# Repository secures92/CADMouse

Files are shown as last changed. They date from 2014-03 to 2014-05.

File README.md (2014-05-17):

CADMouse
========

fully 3D printable CAD-Mouse with host software for solidworks.

CAD-Mouse is connected as Joystick. Windows host software translates Axis movements to Solidworks view translation commands.
(Any standard joystick could be use)

Thingiverse: http://www.thingiverse.com/thing:260830
Warning : some parts have been upgraded, check latest version on github.

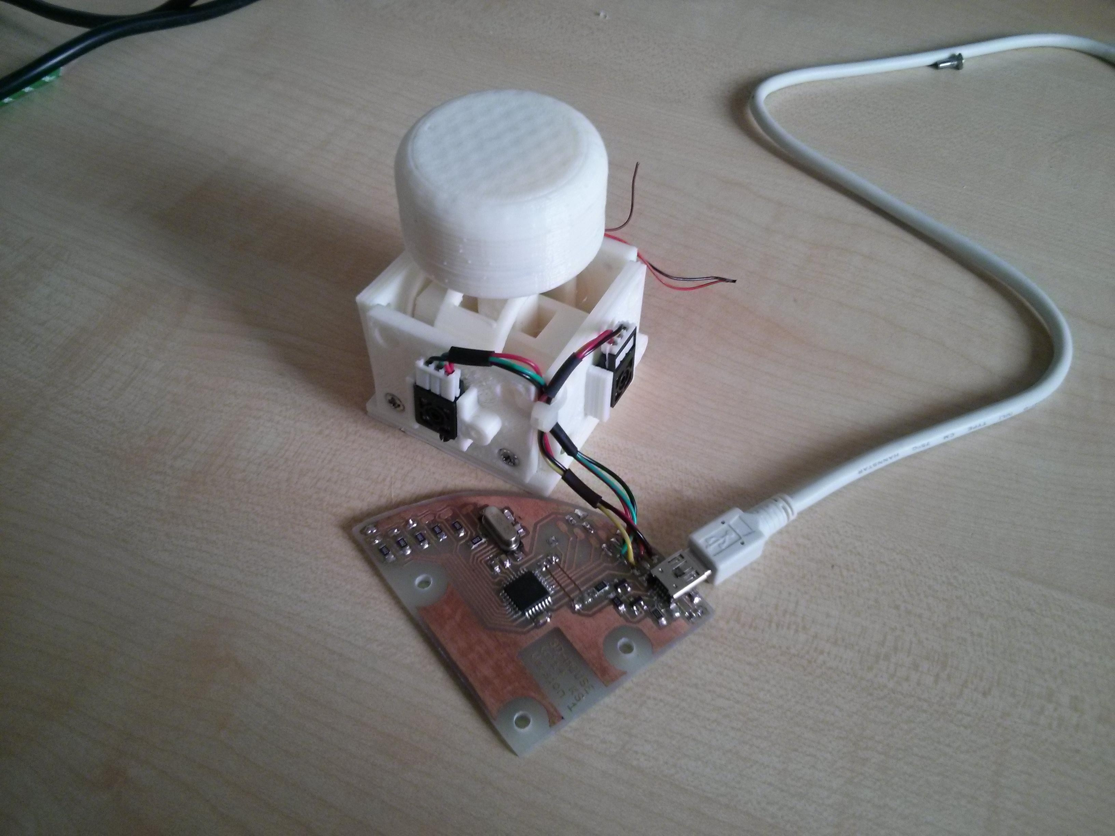
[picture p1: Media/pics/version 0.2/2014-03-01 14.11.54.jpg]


Video
------
New top spring and added translate / zoom :
IMAGE ALT TEXT HERE (http://youtu.be/kaDWCsqc0LQ)

Original demo
IMAGE ALT TEXT HERE (http://youtu.be/4gp94MjgFCs)

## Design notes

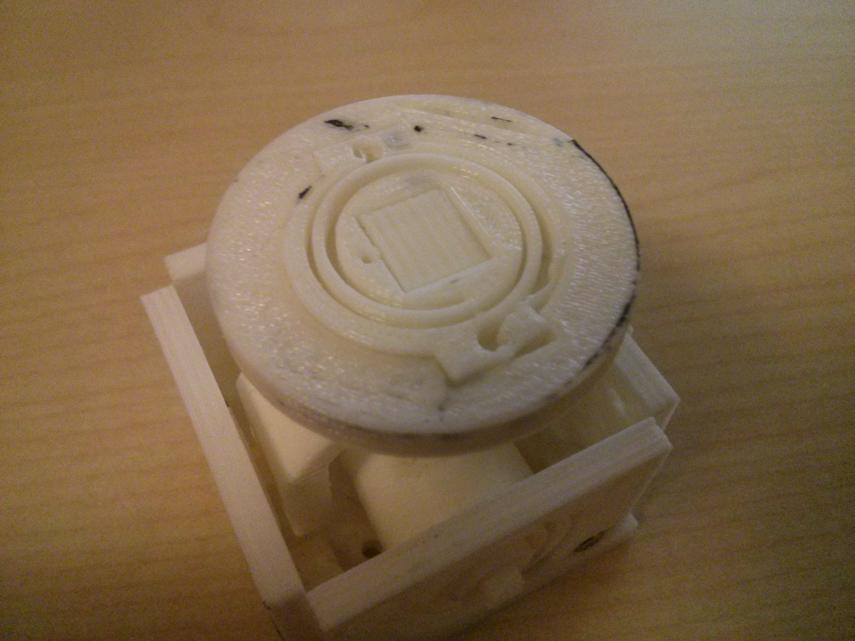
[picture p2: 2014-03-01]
Media/pics/version 0.2/2014-02-27 22.28.41.jpg

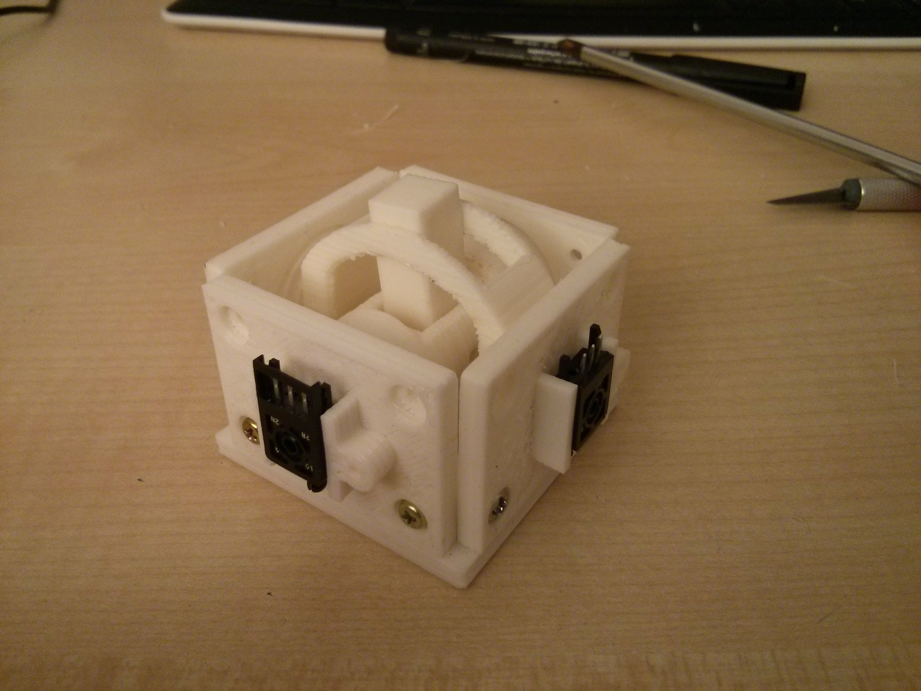
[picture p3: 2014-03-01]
Media/pics/version 0.2/2014-02-24 00.38.57.jpg

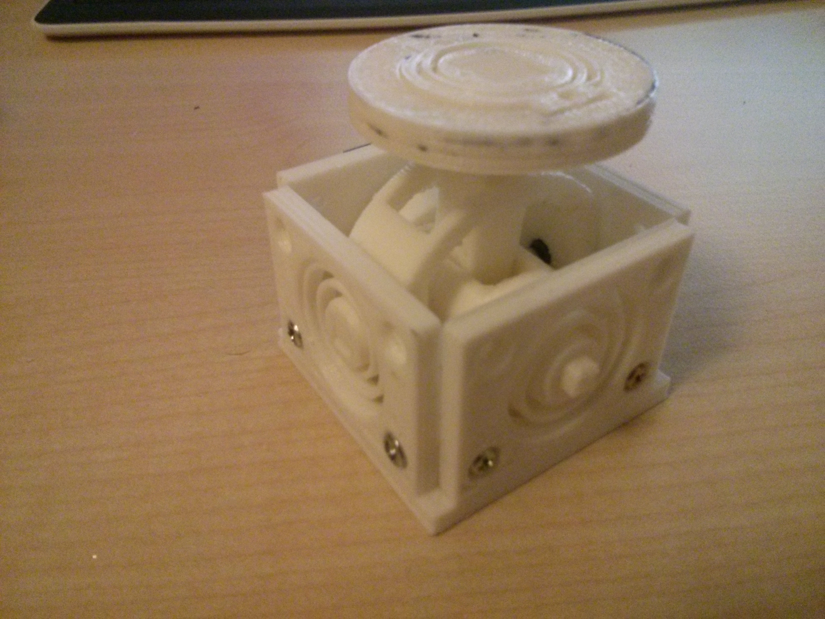
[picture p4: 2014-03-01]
Media/pics/version 0.2/2014-02-27 22.28.56.jpg

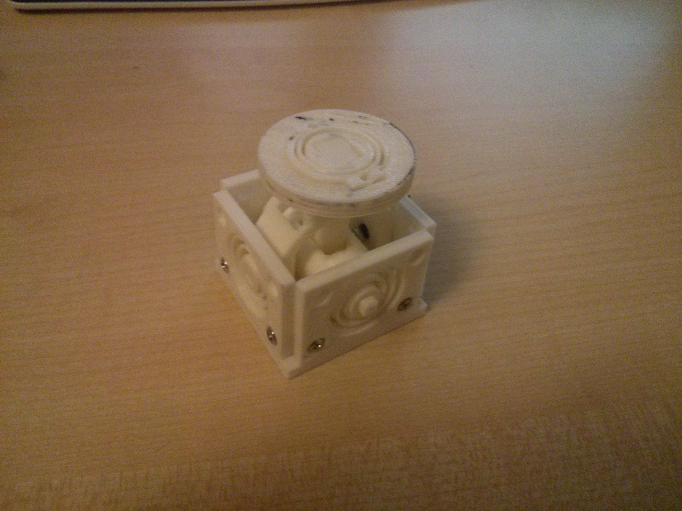
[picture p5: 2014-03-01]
Media/pics/version 0.2/2014-02-27 22.28.31.jpg

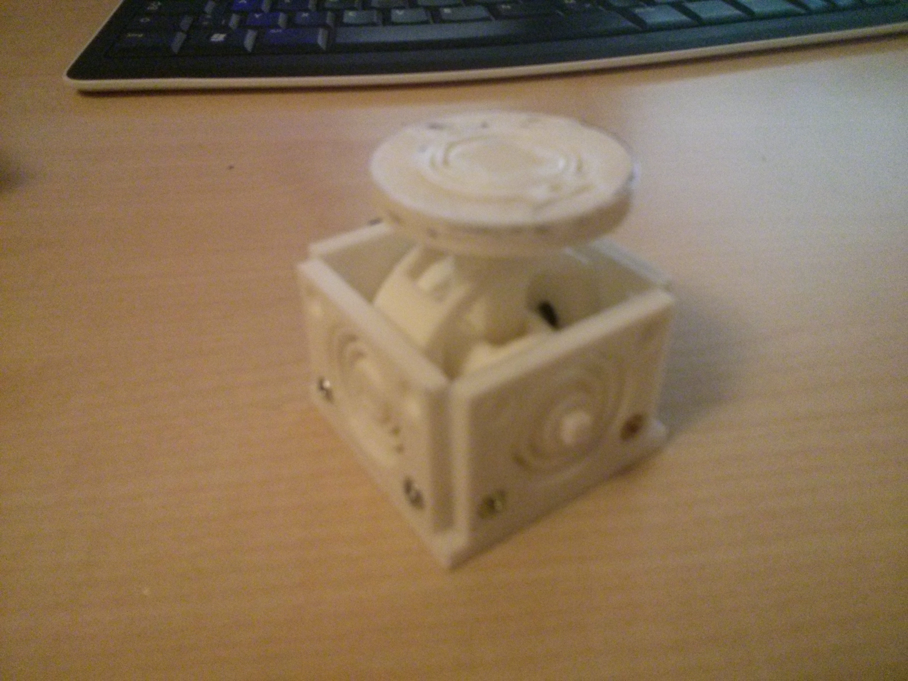
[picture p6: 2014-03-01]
Media/pics/version 0.2/2014-02-27 22.29.02.jpg

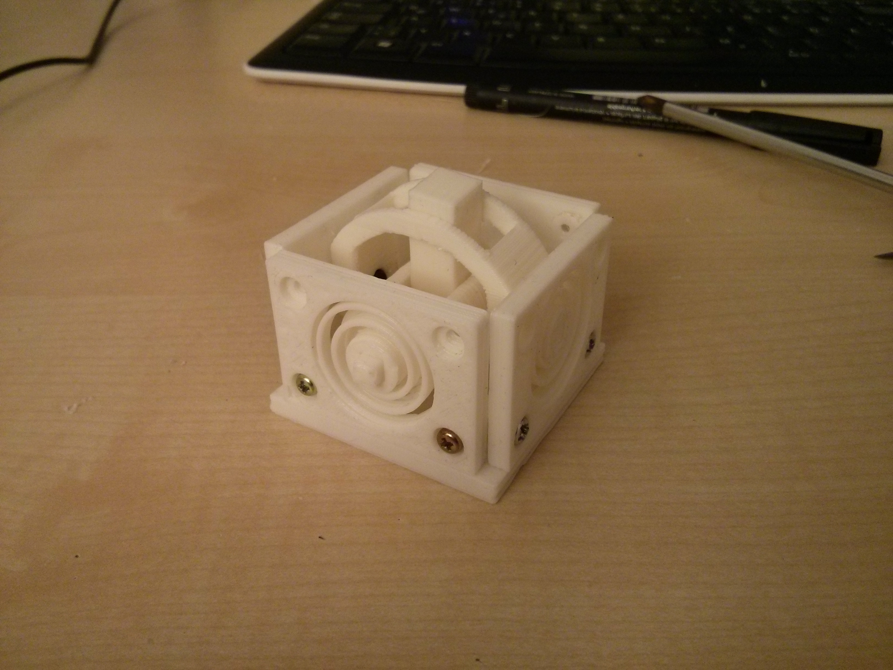
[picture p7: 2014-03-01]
Media/pics/version 0.2/2014-02-24 00.38.48.jpg

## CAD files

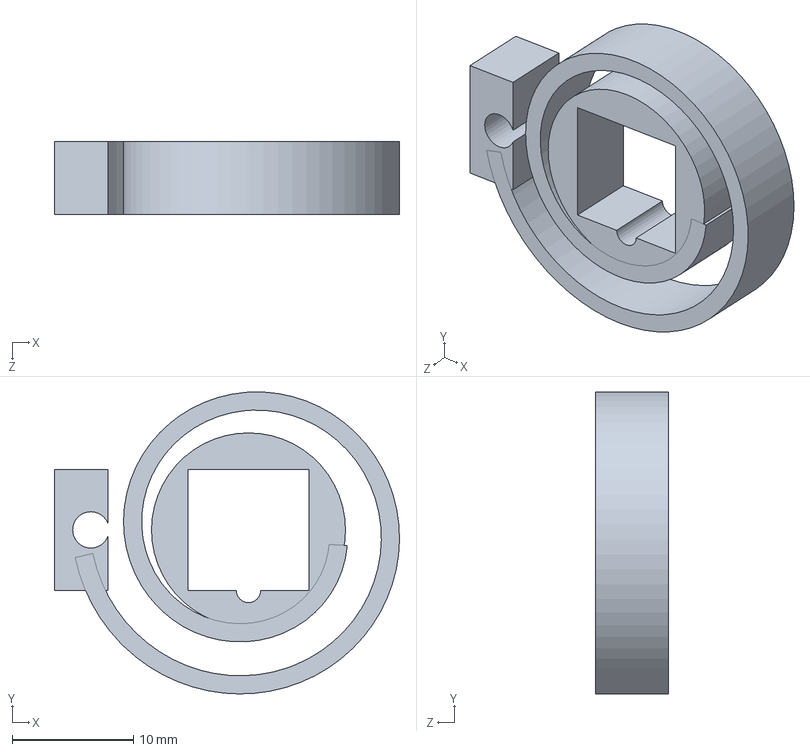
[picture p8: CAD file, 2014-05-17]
SolidWorks/Version 0.4/top_spring_3.SLDPRT
28.5 x 24.9 x 6.00 mm

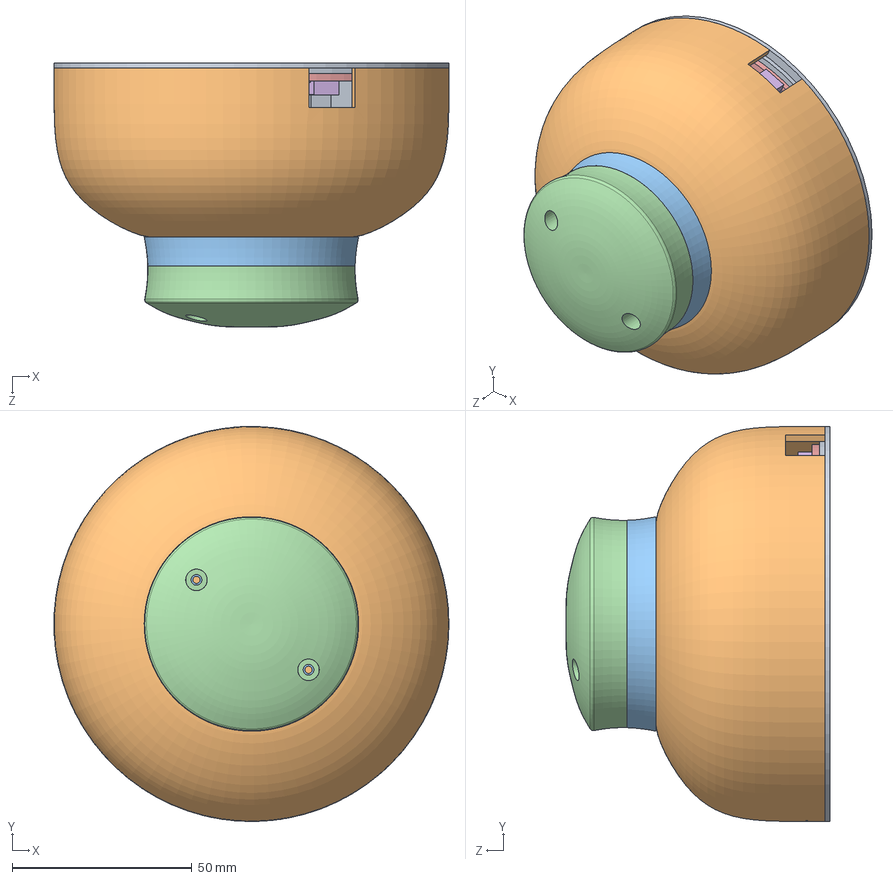
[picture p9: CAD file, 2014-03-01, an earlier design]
SolidWorks/Version 0.1/3DMaus.SLDASM
110.0 x 110.0 x 73.6 mm
bottom
case
KnobBottom
KnobTop
pcb
components

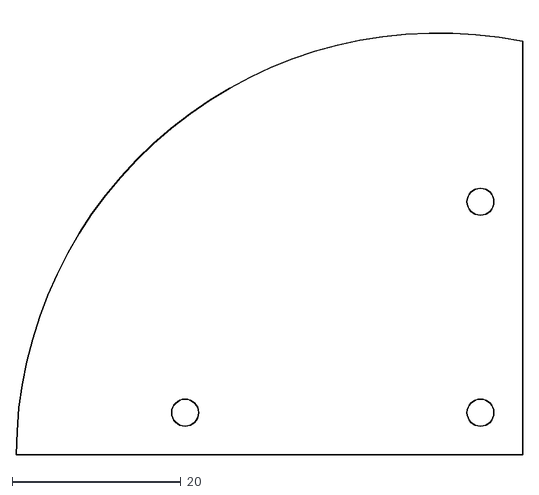
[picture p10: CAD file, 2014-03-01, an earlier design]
Eagle/Version 0.1/AtMega88.dxf
60.0 x 52.0

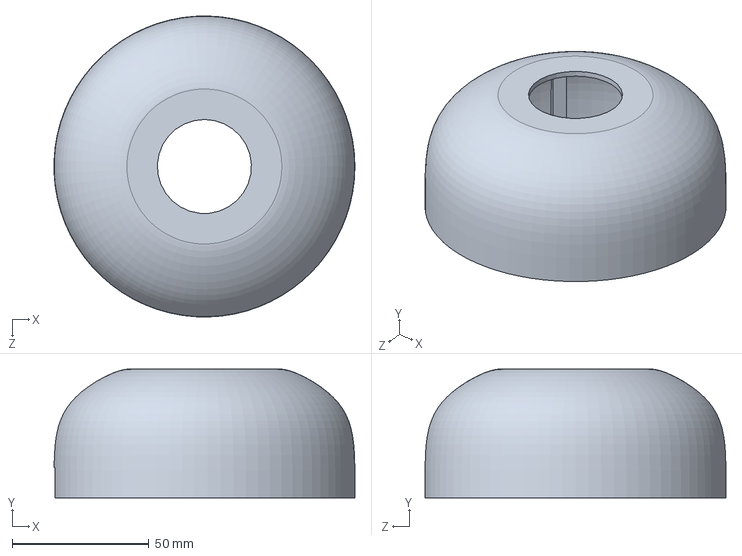
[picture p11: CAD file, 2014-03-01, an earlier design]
SolidWorks/Version 0.1/case.SLDPRT
109.9 x 47.0 x 110.0 mm

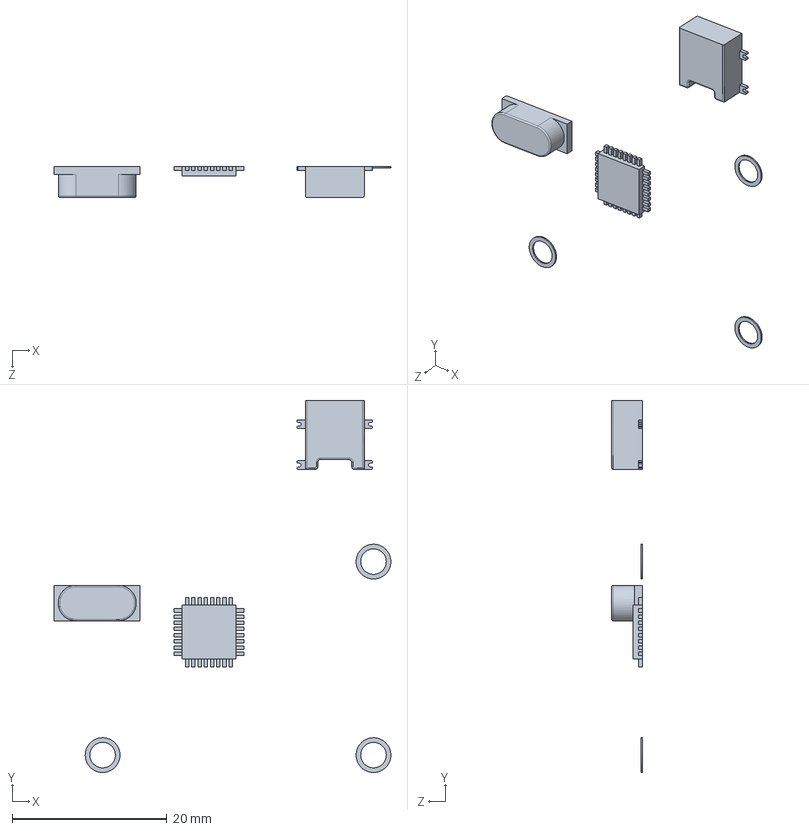
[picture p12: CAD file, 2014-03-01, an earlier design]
SolidWorks/Version 0.1/pcb/components.SLDPRT
43.5 x 48.1 x 4.00 mm

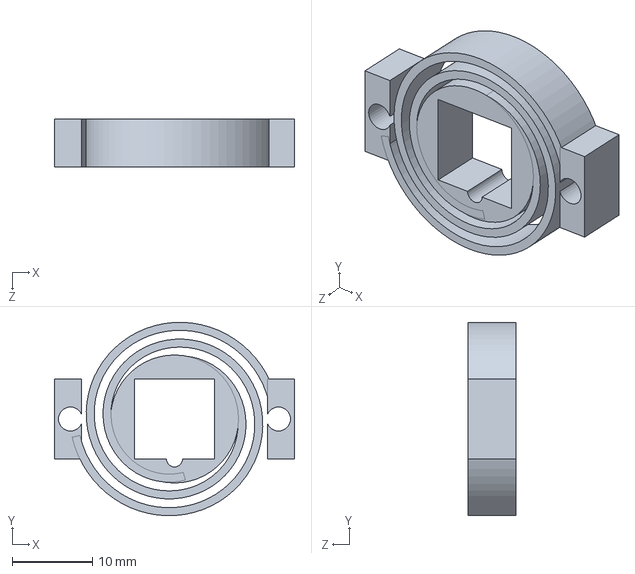
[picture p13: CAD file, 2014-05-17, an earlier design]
SolidWorks/Version 0.3/top_spring_2.SLDPRT
30.0 x 24.2 x 6.00 mm

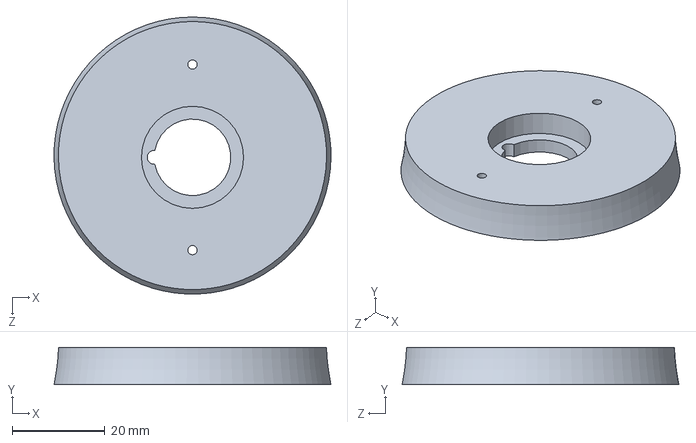
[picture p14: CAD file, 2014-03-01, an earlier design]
SolidWorks/Version 0.1/KnobBottom.SLDPRT
59.7 x 8.00 x 59.7 mm

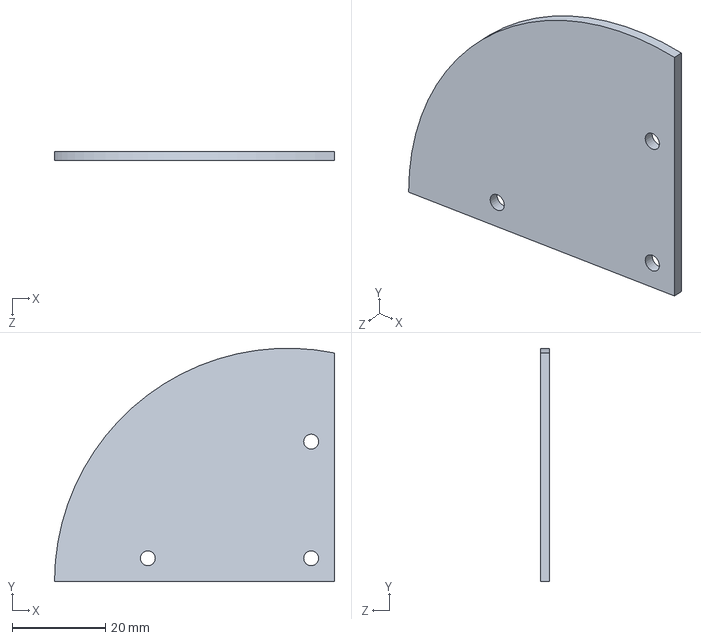
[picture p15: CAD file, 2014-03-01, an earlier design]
SolidWorks/Version 0.1/pcb/pcb.SLDPRT
60.0 x 50.0 x 2.00 mm

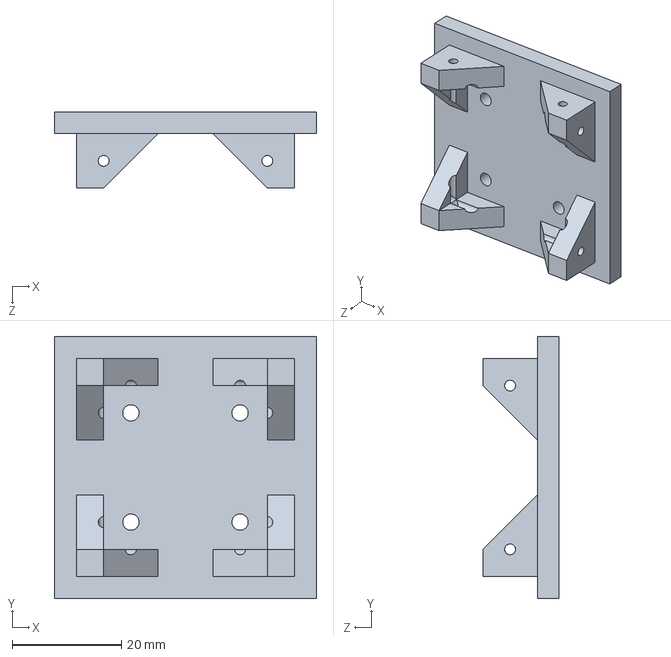
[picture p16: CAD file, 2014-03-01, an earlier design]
SolidWorks/Version 0.2/base.SLDPRT
48.0 x 48.0 x 14.0 mm

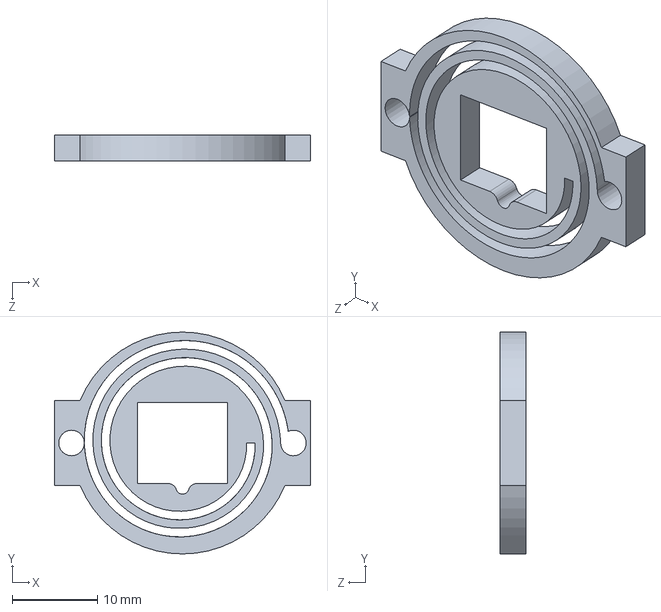
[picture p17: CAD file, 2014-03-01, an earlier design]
SolidWorks/Version 0.2/top_spring.SLDPRT
30.0 x 26.0 x 3.00 mm

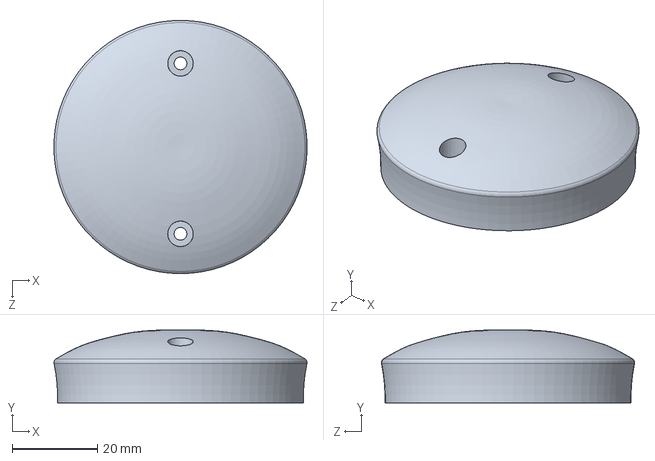
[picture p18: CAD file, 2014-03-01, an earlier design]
SolidWorks/Version 0.1/KnobTop.SLDPRT
59.4 x 17.1 x 59.4 mm

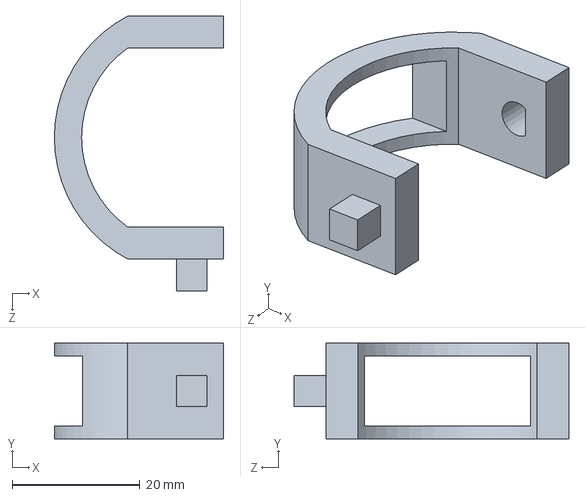
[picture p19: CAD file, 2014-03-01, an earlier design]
SolidWorks/Version 0.2/rod-bow.SLDPRT
26.5 x 15.0 x 43.0 mm

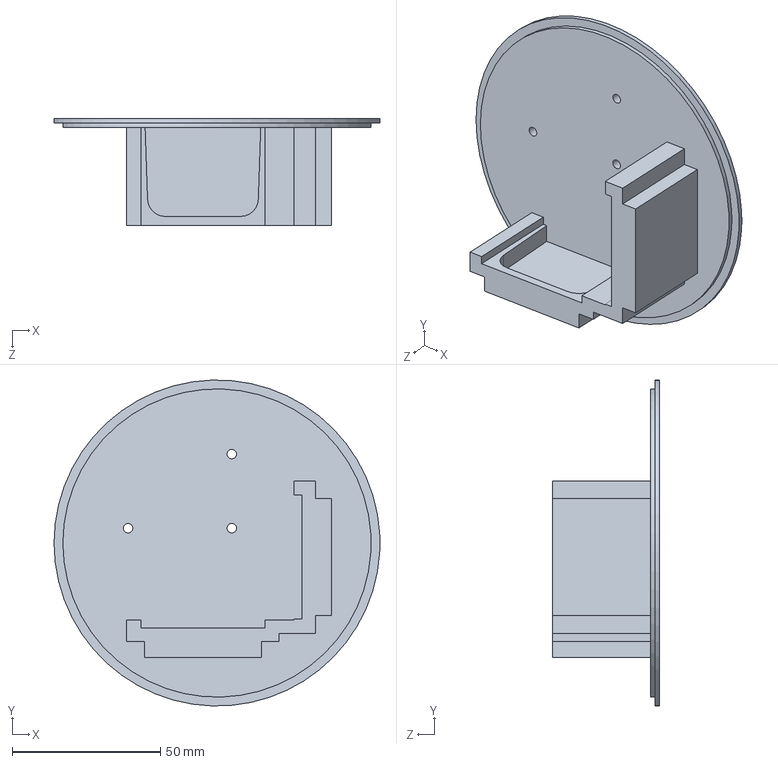
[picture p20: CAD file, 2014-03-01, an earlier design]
SolidWorks/Version 0.1/bottom_1.SLDPRT
110.0 x 110.0 x 36.0 mm

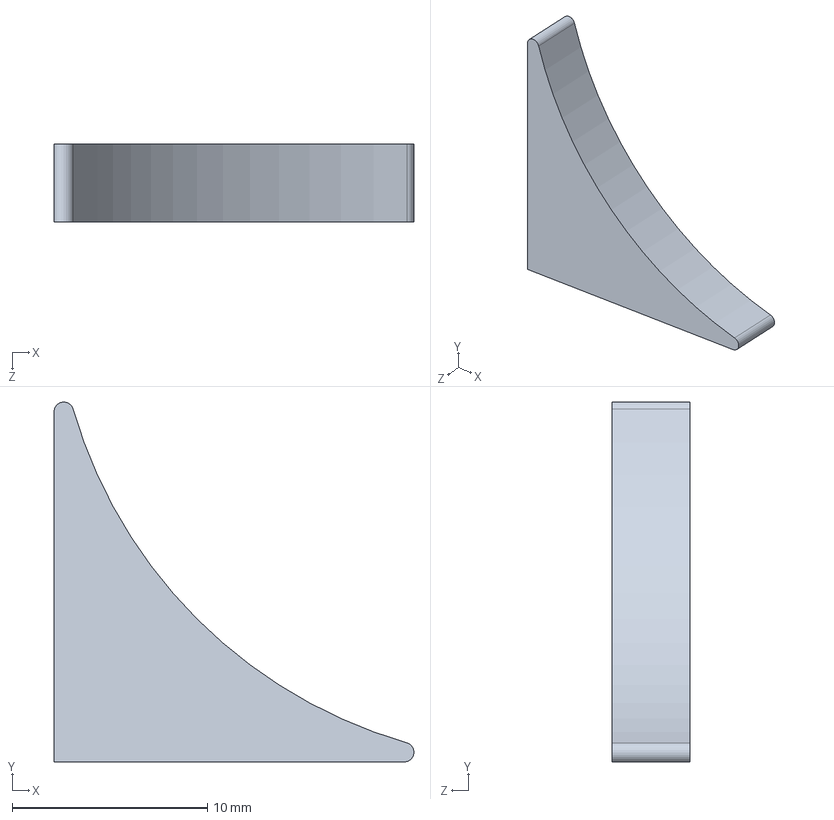
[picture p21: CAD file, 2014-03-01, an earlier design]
SolidWorks/Version 0.2/top.SLDPRT
18.4 x 18.4 x 4.00 mm

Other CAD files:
SolidWorks/Version 0.1/bottom.SLDPRT
SolidWorks/Version 0.2/spring_wall.SLDPRT
SolidWorks/Version 0.1/connector.SLDPRT
Eagle/Version 0.1/AtMega88_.dxf
SolidWorks/Version 0.1/STL/KnobBottom.STL
SolidWorks/Version 0.1/STL/KnobTop.STL
SolidWorks/Version 0.1/STL/bottom.STL
SolidWorks/Version 0.1/STL/case.STL
SolidWorks/Version 0.1/STL/connector.STL
SolidWorks/Version 0.1/bottom_alt.SLDPRT
SolidWorks/Version 0.2/case.SLDPRT
SolidWorks/Version 0.2/knob_bottom.SLDPRT
SolidWorks/Version 0.2/knob_top.SLDPRT
SolidWorks/Version 0.2/plate_bottom.SLDPRT
SolidWorks/Version 0.2/poti_spring_wall.SLDPRT
SolidWorks/Version 0.2/poti_wall.SLDPRT
SolidWorks/Version 0.2/rod.SLDPRT
SolidWorks/Version 0.2/stick.SLDPRT
SolidWorks/Version 0.2/stl/base.STL
SolidWorks/Version 0.2/stl/case.STL
SolidWorks/Version 0.2/stl/knob_bottom.STL
SolidWorks/Version 0.2/stl/knob_top.STL
SolidWorks/Version 0.2/stl/poti_wall.STL
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

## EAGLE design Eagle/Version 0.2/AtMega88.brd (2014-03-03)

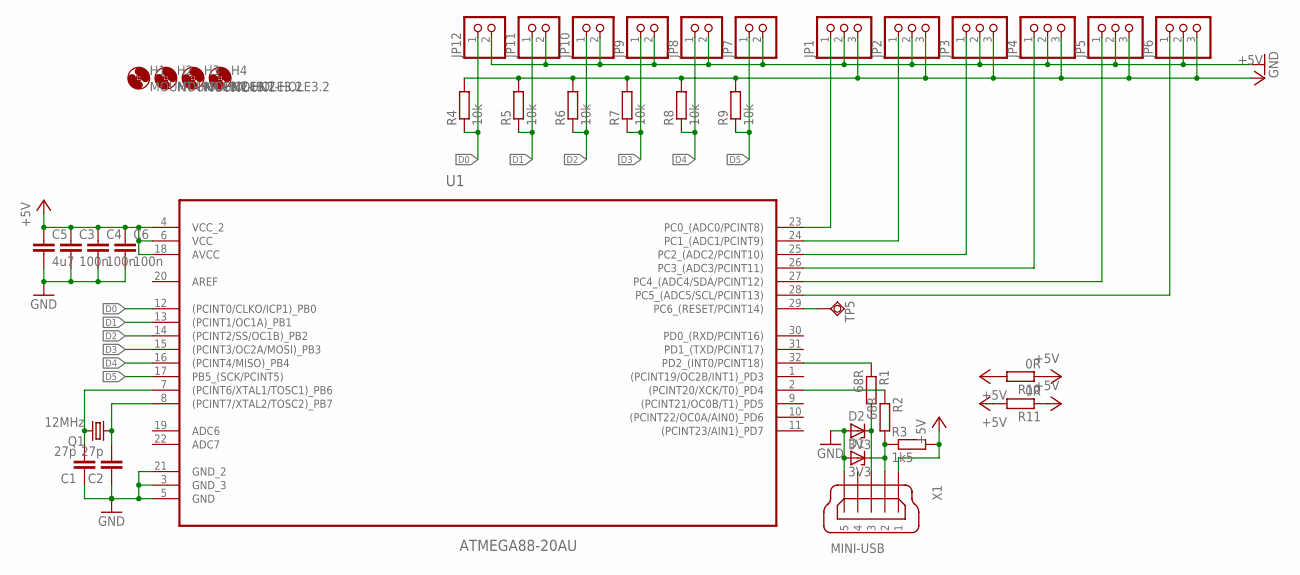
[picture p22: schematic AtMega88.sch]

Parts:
C1, C2: 27p; C0805
C3, C4, C6: 100n; C0805
C5: 4u7; C0805
D1, D2: 3V3; SOT23
H1, H2, H3, H4: MOUNT-HOLE3.2; 3,2
JP1, JP2, JP3, JP4, JP5, JP6: PINHD-1X3; 1X03
JP7, JP8, JP9, JP10, JP11, JP12: PINHD-1X2; 1X02
Q1: 12MHz; CSM-7X-DU
R1, R2: 68R; R1206
R3: 1k5; R1206
R4, R5, R6, R7, R8, R9: 10k; R1206
R10, R11: 0R; R1206
TP5: TPSQTP20SQ; TP20SQ
U1: ATMEGA88-20AU; QFP80P900X900X120-32N
X1: MINI-USB; UX60A-MB-5ST

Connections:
+5V: C3.1, C4.1, C5.1, C6.1, JP1.3, JP2.3, JP3.3, JP4.3, JP5.3, JP6.3, R3.2, R4.2, R5.2, R6.2, R7.2, R8.2, R9.2, R10.1, R10.2, R11.1, R11.2, U1.4 (VCC_2), U1.6 (VCC), U1.18 (AVCC), X1.1
A0: JP1.1, U1.23 (PC0_(ADC0/PCINT8))
A1: JP2.1, U1.24 (PC1_(ADC1/PCINT9))
A2: JP3.1, U1.25 (PC2_(ADC2/PCINT10))
A3: JP4.1, U1.26 (PC3_(ADC3/PCINT11))
A4: JP5.1, U1.27 (PC4_(ADC4/SDA/PCINT12))
A5: JP6.1, U1.28 (PC5_(ADC5/SCL/PCINT13))
D0: JP12.1, R4.1, U1.12 ((PCINT0/CLKO/ICP1)_PB0)
D1: JP11.1, R5.1, U1.13 ((PCINT1/OC1A)_PB1)
D2: JP10.1, R6.1, U1.14 ((PCINT2/SS/OC1B)_PB2)
D3: JP9.1, R7.1, U1.15 ((PCINT3/OC2A/MOSI)_PB3)
D4: JP8.1, R8.1, U1.16 ((PCINT4/MISO)_PB4)
D5: JP7.1, R9.1, U1.17 (PB5_(SCK/PCINT5))
GND: C1.1, C2.1, C3.2, C4.2, C5.2, C6.2, D1.1 (A), D2.1 (A), JP1.2, JP2.2, JP3.2, JP4.2, JP5.2, JP6.2, JP7.2, JP8.2, JP9.2, JP10.2, JP11.2, JP12.2, U1.3 (GND_3), U1.5 (GND), U1.21 (GND_2), X1.5
unnamed: C1.2, Q1.2, U1.7 ((PCINT6/XTAL1/TOSC1)_PB6)
unnamed: C2.2, Q1.1, U1.8 ((PCINT7/XTAL2/TOSC2)_PB7)
unnamed: R1.1, U1.32 (PD2_(INT0/PCINT18))
unnamed: R2.1, U1.2 ((PCINT20/XCK/T0)_PD4)
unnamed: D2.3 (C), R1.2, X1.3
unnamed: D1.3 (C), R2.2, R3.1, X1.2
unnamed: TP5.TP, U1.29 (PC6_(RESET/PCINT14))

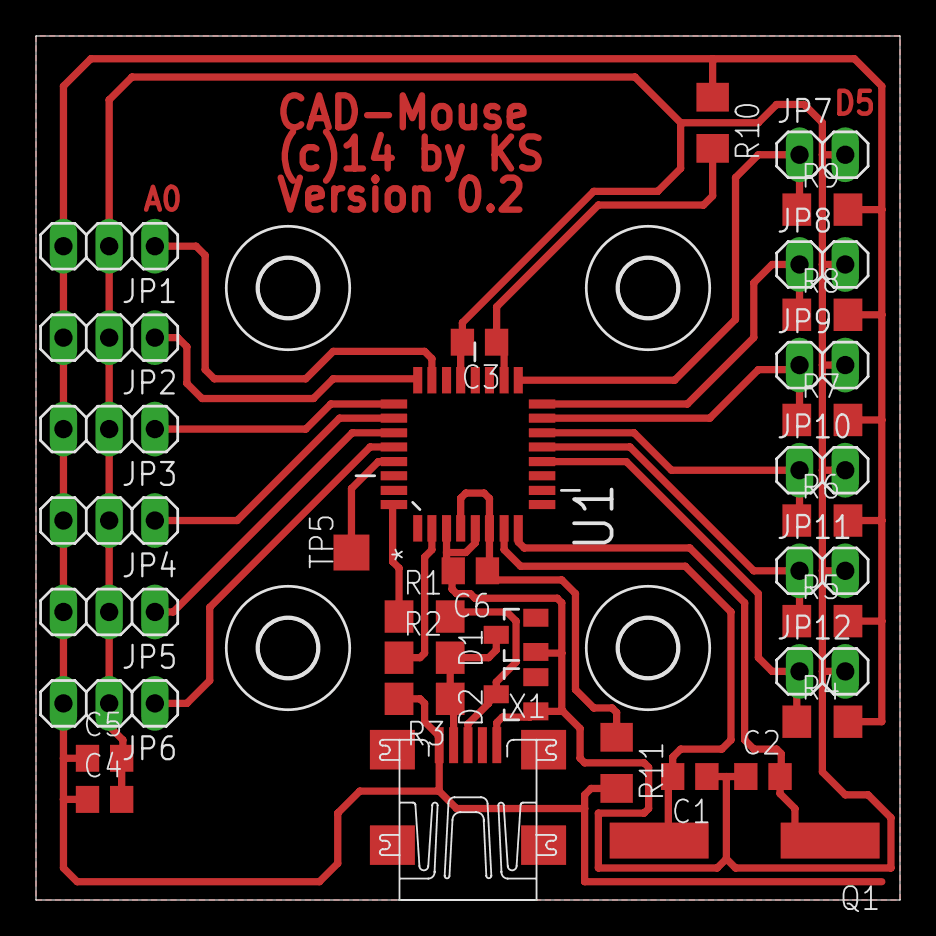
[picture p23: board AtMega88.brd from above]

Board: 2 copper layers, 48.0 x 48.0 mm, 39 parts (0 on the bottom side), 21 nets.

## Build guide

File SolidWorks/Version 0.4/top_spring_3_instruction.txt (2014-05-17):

This new spring is to be use without knob bottom.

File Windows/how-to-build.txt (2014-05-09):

install slimDX runtime
add reference from solidworks dll :
SolidWorks.Interop.sldworks.dll

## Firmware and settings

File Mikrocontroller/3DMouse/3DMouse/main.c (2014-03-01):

#include "main.h"

#include <avr/io.h>
#include <avr/wdt.h>
#include <avr/interrupt.h> /* for sei() */
#include <util/delay.h> /* for _delay_ms() */

#include <avr/pgmspace.h>  /* required by usbdrv.h */
#include "usbdrv/usbdrv.h"
#include "usbdrv/oddebug.h"
#include "ppm.h"
#include "mouse.h"

/* ------------------------------------------------------------------------- */
/* ----------------------------- USB interface ----------------------------- */
/* ------------------------------------------------------------------------- */

PROGMEM char const usbHidReportDescriptor[50] = { /* USB report descriptor, size must match usbconfig.h */
	0x05, 0x01, // USAGE_PAGE (Generic Desktop)
	0x15, 0x00, // LOGICAL_MINIMUM (0)
	0x26, 0xff, 0x00,  // LOGICAL_MAXIMUM (255)
	0x75, 0x08, // REPORT_SIZE (6)
	0x09, 0x04, // USAGE (Joystick)
	0xa1, 0x01, // COLLECTION (Application)
	0x09, 0x01, //  USAGE (Pointer)
	0xa1, 0x00, //  COLLECTION (Physical)
	0x09, 0x30, // USAGE (X)
	0x09, 0x31, // USAGE (Y)
	0x95, 0x02, // REPORT_COUNT (2)
	0x81, 0x82, // INPUT (Data,Var,Abs,Vol)
	0xc0, //  END_COLLECTION
	0xa1, 0x00, //  COLLECTION (Physical)
	0x09, 0x32, // USAGE (Z)
	0x09, 0x33, // USAGE (Rx)
	0x95, 0x02, // REPORT_COUNT (2)
	0x81, 0x82, // INPUT (Data,Var,Abs,Vol)
	0xc0, //  END_COLLECTION
	0x09, 0x34, //  USAGE (Ry)
	0x09, 0x35, //  USAGE (Rz)
	0x09, 0x36, //  USAGE (Slider)
	0x09, 0x37, //  USAGE (Dial)
	0x95, 0x04, //  REPORT_COUNT (2)
	0x81, 0x82, //  INPUT (Data,Var,Abs,Vol)
	0xc0 // END_COLLECTION
};
//PROGMEM const char usbHidReportDescriptor[50] = {
	//0x05, 0x01,                    // USAGE_PAGE (Generic Desktop)
	//0x09, 0x02,                    // USAGE (Mouse)
	//0xa1, 0x01,                    // COLLECTION (Application)
	//0x09, 0x01,                    //   USAGE (Pointer)
	//0xa1, 0x00,                    //   COLLECTION (Physical)
	//0x05, 0x09,                    //     USAGE_PAGE (Button)
	//0x19, 0x01,                    //     USAGE_MINIMUM (Button 1)
	//0x29, 0x03,                    //     USAGE_MAXIMUM (Button 3)
	//0x15, 0x00,                    //     LOGICAL_MINIMUM (0)
	//0x25, 0x01,                    //     LOGICAL_MAXIMUM (1)
	//0x95, 0x03,                    //     REPORT_COUNT (3)
	//0x75, 0x01,                    //     REPORT_SIZE (1)
	//0x81, 0x02,                    //     INPUT (Data,Var,Abs)
	//0x95, 0x01,                    //     REPORT_COUNT (1)
	//0x75, 0x05,                    //     REPORT_SIZE (5)
	//0x81, 0x03,                    //     INPUT (Cnst,Var,Abs)
	//0x05, 0x01,                    //     USAGE_PAGE (Generic Desktop)
	//0x09, 0x30,                    //     USAGE (X)
	//0x09, 0x31,                    //     USAGE (Y)
	//0x15, 0x81,                    //     LOGICAL_MINIMUM (-127)
	//0x25, 0x7f,                    //     LOGICAL_MAXIMUM (127)
	//0x75, 0x08,                    //     REPORT_SIZE (8)
	//0x95, 0x02,                    //     REPORT_COUNT (2)
	//0x81, 0x06,                    //     INPUT (Data,Var,Rel)
	//0xc0,                          //   END_COLLECTION
	//0xc0                           // END_COLLECTION
//};
//

static uchar reportBuffer[8];
static uchar idleRate;  /* repeat rate for keyboards, never used for mice */


/* ------------------------------------------------------------------------- */

usbMsgLen_t usbFunctionSetup(uchar data[8])
{
	usbRequest_t *rq = (void *)data;

	if((rq->bmRequestType & USBRQ_TYPE_MASK) == USBRQ_TYPE_CLASS){ /* class request type */
		DBG1(0x50, &rq->bRequest, 1);  /* debug output: print our request */
		if(rq->bRequest == USBRQ_HID_GET_REPORT){ /* wValue: ReportType (highbyte), ReportID (lowbyte) */
			/* we only have one report type, so don't look at wValue */
			usbMsgPtr = (void *)&reportBuffer;
			return sizeof(reportBuffer);
			}else if(rq->bRequest == USBRQ_HID_GET_IDLE){
			usbMsgPtr = &idleRate;
			return 1;
			}else if(rq->bRequest == USBRQ_HID_SET_IDLE){
			idleRate = rq->wValue.bytes[1];
		}
		}else{
		/* no vendor specific requests implemented */
	}
	return 0;  /* default for not implemented requests: return no data back to host */
}
//
//uchar usbFunctionSetup(uchar data[8])
//{
	//usbRequest_t    *rq = (void *)data;
//
	//usbMsgPtr = reportBuffer;
	//if((rq->bmRequestType & USBRQ_TYPE_MASK) == USBRQ_TYPE_CLASS){
		//if(rq->bRequest == USBRQ_HID_GET_REPORT){
			//return sizeof(reportBuffer);
		//}
		//}else{
		///* no vendor specific requests implemented */
	//}
	//return 0;
//}


/* ------------------------------------------------------------------------- */

int main(void) {
	wdt_enable(WDTO_1S);

	//odDebugInit();
	//DBG1(0x00, 0, 0);  /* debug output: main starts */

	mouseInit();

	usbInit();

	usbDeviceDisconnect(); /* enforce re-enumeration, do this while interrupts are disabled! */
	uchar i = 0;
	while(--i){  /* fake USB disconnect for > 250 ms */
		wdt_reset();
		_delay_ms(1);
	}
	usbDeviceConnect();

	sei();
	//DBG1(0x01, 0, 0);  /* debug output: main loop starts */
	
	
	for(;;){ /* main event loop */
		//DBG1(0x02, 0, 0);  /* debug output: main loop iterates */
		wdt_reset();
		usbPoll();
		
		reportBuffer[0]=getXAxis();
		reportBuffer[1]=getYAxis();
		reportBuffer[2]=getZAxis();
		
		if(usbInterruptIsReady()){
		// called after every poll of the interrupt endpoint
		//DBG1(0x03, 0, 0);  // debug output: interrupt report prepared
		usbSetInterrupt((void *)&reportBuffer, sizeof(reportBuffer));
		}
	}
}

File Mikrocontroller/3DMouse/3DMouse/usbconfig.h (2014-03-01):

/* Name: usbconfig.h
 * Project: V-USB, virtual USB port for Atmel's(r) AVR(r) microcontrollers
 * Author: Christian Starkjohann
 * Creation Date: 2005-04-01
 * Tabsize: 4
 * Copyright: (c) 2005 by OBJECTIVE DEVELOPMENT Software GmbH
 * License: GNU GPL v2 (see License.txt), GNU GPL v3 or proprietary (CommercialLicense.txt)
 * This Revision: $Id: usbconfig-prototype.h 785 2010-05-30 17:57:07Z cs $
 */

#ifndef __usbconfig_h_included__
#define __usbconfig_h_included__

/*
General Description:
This file is an example configuration (with inline documentation) for the USB
driver. It configures V-USB for USB D+ connected to Port D bit 2 (which is
also hardware interrupt 0 on many devices) and USB D- to Port D bit 4. You may
wire the lines to any other port, as long as D+ is also wired to INT0 (or any
other hardware interrupt, as long as it is the highest level interrupt, see
section at the end of this file).
*/

/* ---------------------------- Hardware Config ---------------------------- */

#define USB_CFG_IOPORTNAME      D
/* This is the port where the USB bus is connected. When you configure it to
 * "B", the registers PORTB, PINB and DDRB will be used.
 */
#define USB_CFG_DMINUS_BIT      4
/* This is the bit number in USB_CFG_IOPORT where the USB D- line is connected.
 * This may be any bit in the port.
 */
#define USB_CFG_DPLUS_BIT       2
/* This is the bit number in USB_CFG_IOPORT where the USB D+ line is connected.
 * This may be any bit in the port. Please note that D+ must also be connected
 * to interrupt pin INT0! [You can also use other interrupts, see section
 * "Optional MCU Description" below, or you can connect D- to the interrupt, as
 * it is required if you use the USB_COUNT_SOF feature. If you use D- for the
 * interrupt, the USB interrupt will also be triggered at Start-Of-Frame
 * markers every millisecond.]
 */
#define USB_CFG_CLOCK_KHZ       (F_CPU/1000)
/* Clock rate of the AVR in kHz. Legal values are 12000, 12800, 15000, 16000,
 * 16500, 18000 and 20000. The 12.8 MHz and 16.5 MHz versions of the code
 * require no crystal, they tolerate +/- 1% deviation from the nominal
 * frequency. All other rates require a precision of 2000 ppm and thus a
 * crystal!
 * Since F_CPU should be defined to your actual clock rate anyway, you should
 * not need to modify this setting.
 */
#define USB_CFG_CHECK_CRC       0
/* Define this to 1 if you want that the driver checks integrity of incoming
 * data packets (CRC checks). CRC checks cost quite a bit of code size and are
 * currently only available for 18 MHz crystal clock. You must choose
 * USB_CFG_CLOCK_KHZ = 18000 if you enable this option.
 */

/* ----------------------- Optional Hardware Config ------------------------ */

/* #define USB_CFG_PULLUP_IOPORTNAME   D */
/* If you connect the 1.5k pullup resistor from D- to a port pin instead of
 * V+, you can connect and disconnect the device from firmware by calling
 * the macros usbDeviceConnect() and usbDeviceDisconnect() (see usbdrv.h).
 * This constant defines the port on which the pullup resistor is connected.
 */
/* #define USB_CFG_PULLUP_BIT          4 */
/* This constant defines the bit number in USB_CFG_PULLUP_IOPORT (defined
 * above) where the 1.5k pullup resistor is connected. See description
 * above for details.
 */

/* --------------------------- Functional Range ---------------------------- */
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

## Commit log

2014-03-03 Electronics Version 0.2
    Updated Electronics to Version 0.2
    [3d-mouse.SLDASM, AtMega88.brd, AtMega88.sch]
2014-05-08 add Z axis to zoom, make it work for every version of solidworks, improve smoothness by increasing refresh rate
2014-05-09 new top spring with 2 spring instead of 1
    [top_spring_2.SLDPRT, top_spring_2.STL]
2014-05-11 added button support to zoom / translate added model rotation on Z axe added controls to modify threshold value and factor
2014-05-16 new stronger version of spring 0.4 to be use without knob bottom
    [top_spring_2.SLDPRT, top_spring_2.STL, top_spring_3.SLDPRT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]
